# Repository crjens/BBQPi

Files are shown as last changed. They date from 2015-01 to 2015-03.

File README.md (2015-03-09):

BBQPi
=====

Raspberry Pi BBQ meter

Install Instructions
--------------------

1. Start with latest Raspian image from http://downloads.raspberrypi.org/raspbian_latest
2. login to Pi with Putty or other 
3. run 'sudo raspi-config' 
	1. set locale and timezone under internationalisation options
	2. enable SPI and I2C under Advanced Options
	3. expand filesystem
4. Enable I2C by adding the following two lines to /etc/modules
	1. i2c-bcm2708 
	2. i2c-dev
5. Install nodejs:
	1.	wget http://nodejs.org/dist/v0.10.28/node-v0.10.28-linux-arm-pi.tar.gz
	2.	tar -xvzf node-v0.10.28-linux-arm-pi.tar.gz
	3.  create symbolic links to node and npm
		1.	sudo ln -s /home/pi/node-v0.10.28-linux-arm-pi/bin/node /usr/bin/node
		2.	sudo ln -s /home/pi/node-v0.10.28-linux-arm-pi/bin/npm /usr/bin/npm
	4. (both node -v and npm -v should now show current version)
6. Clone BBQPi into app directory
	1. git clone https://github.com/crjens/BBQPi.git app
7. cd into the 'app' directory and type 'npm install'

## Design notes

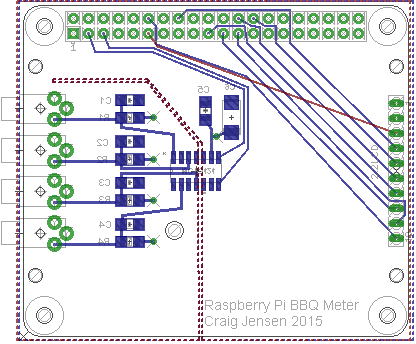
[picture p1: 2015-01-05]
Eagle/BBqP1.png

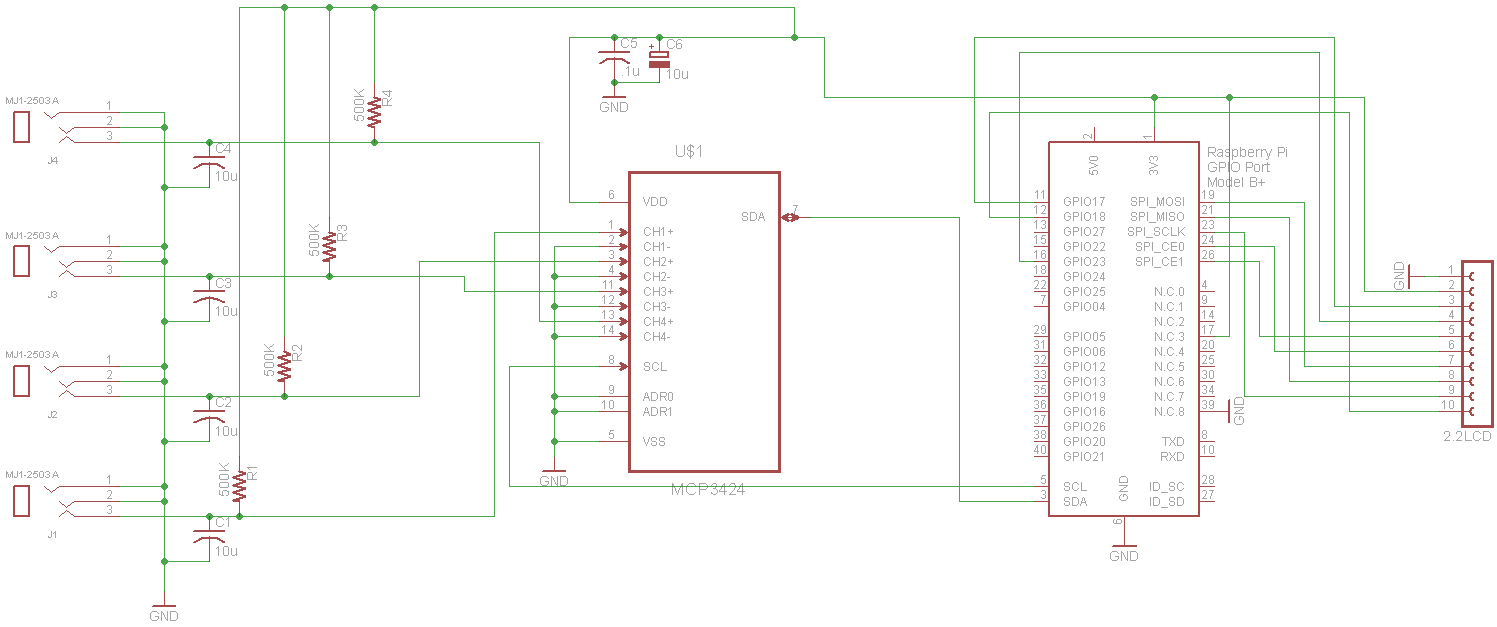
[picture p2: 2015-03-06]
Eagle/BBqP1sch.png

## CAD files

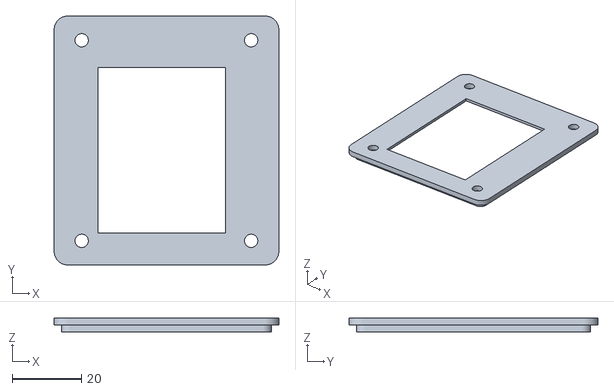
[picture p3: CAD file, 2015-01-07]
3dModels/final pre-critical-measure draft top.stl
65.0 x 72.0 x 4.00

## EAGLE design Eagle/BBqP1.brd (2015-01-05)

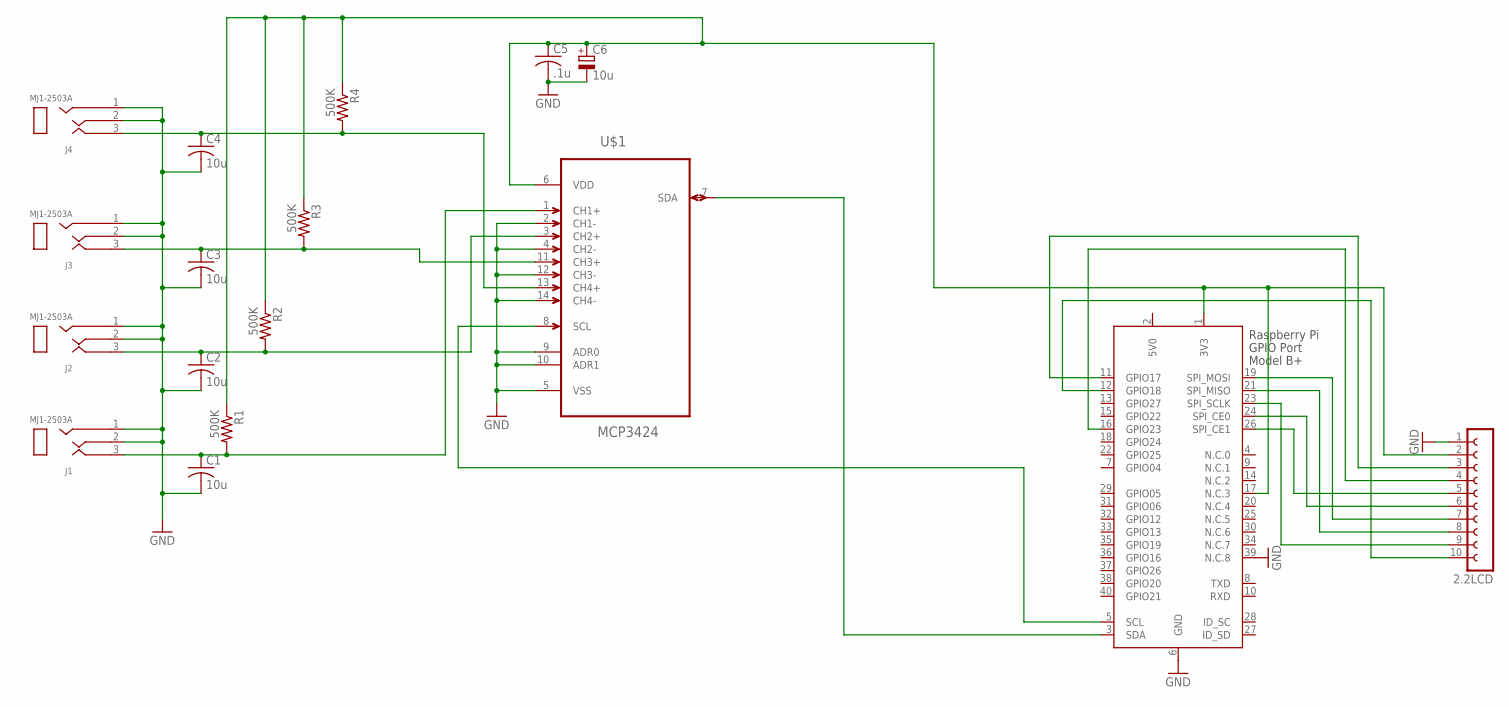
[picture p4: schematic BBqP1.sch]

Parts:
2.2LCD: FE10-1; FE10
C1, C2, C3, C4: 10u; C1206; MPN C1206C106M4RACTU
C5: .1u; C1206; MPN C1206C104K5RACAUTO
C6: 10u; SMC_C; MPN T491C106M016AT
J1, J2, J3, J4: MJ1-2503A
R1, R2, R3, R4: 500K; R1206; MPN CRCW1206510KFKEA
U$1: MCP3424; SOIC127P600X175-14N
X1: RASPI_BOARD_B+_H; RASPI_BOARD_B+HAT

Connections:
3V3: 2.2LCD.2, C5.1, C6.+, R1.1, R2.1, R3.1, R4.1, U$1.6 (VDD), X1.1 (3V3), X1.17 (N.C.3)
5V0: X1.2 (5V0)
GND: 2.2LCD.1, C1.2, C2.2, C3.2, C4.2, C5.2, C6.-, J1.1, J1.2, J2.1, J2.2, J3.1, J3.2, J4.1, J4.2, U$1.2 (CH1-), U$1.4 (CH2-), U$1.5 (VSS), U$1.9 (ADR0), U$1.10 (ADR1), U$1.12 (CH3-), U$1.14 (CH4-), X1.6 (GND), X1.39 (N.C.8)
unnamed: C4.1, J4.3, R4.2, U$1.13 (CH4+)
unnamed: 2.2LCD.10, X1.12 (GPIO18)
unnamed: C3.1, J3.3, R3.2, U$1.11 (CH3+)
unnamed: C2.1, J2.3, R2.2, U$1.3 (CH2+)
unnamed: C1.1, J1.3, R1.2, U$1.1 (CH1+)
unnamed: 2.2LCD.4, X1.16 (GPIO23)
unnamed: 2.2LCD.8, X1.21 (SPI_MISO)
unnamed: U$1.8 (SCL), X1.5 (SCL)
unnamed: 2.2LCD.7, X1.19 (SPI_MOSI)
unnamed: 2.2LCD.6, X1.24 (SPI_CE0)
unnamed: U$1.7 (SDA), X1.3 (SDA)
unnamed: 2.2LCD.5, X1.26 (SPI_CE1)
unnamed: 2.2LCD.9, X1.23 (SPI_SCLK)
unnamed: 2.2LCD.3, X1.11 (GPIO17)

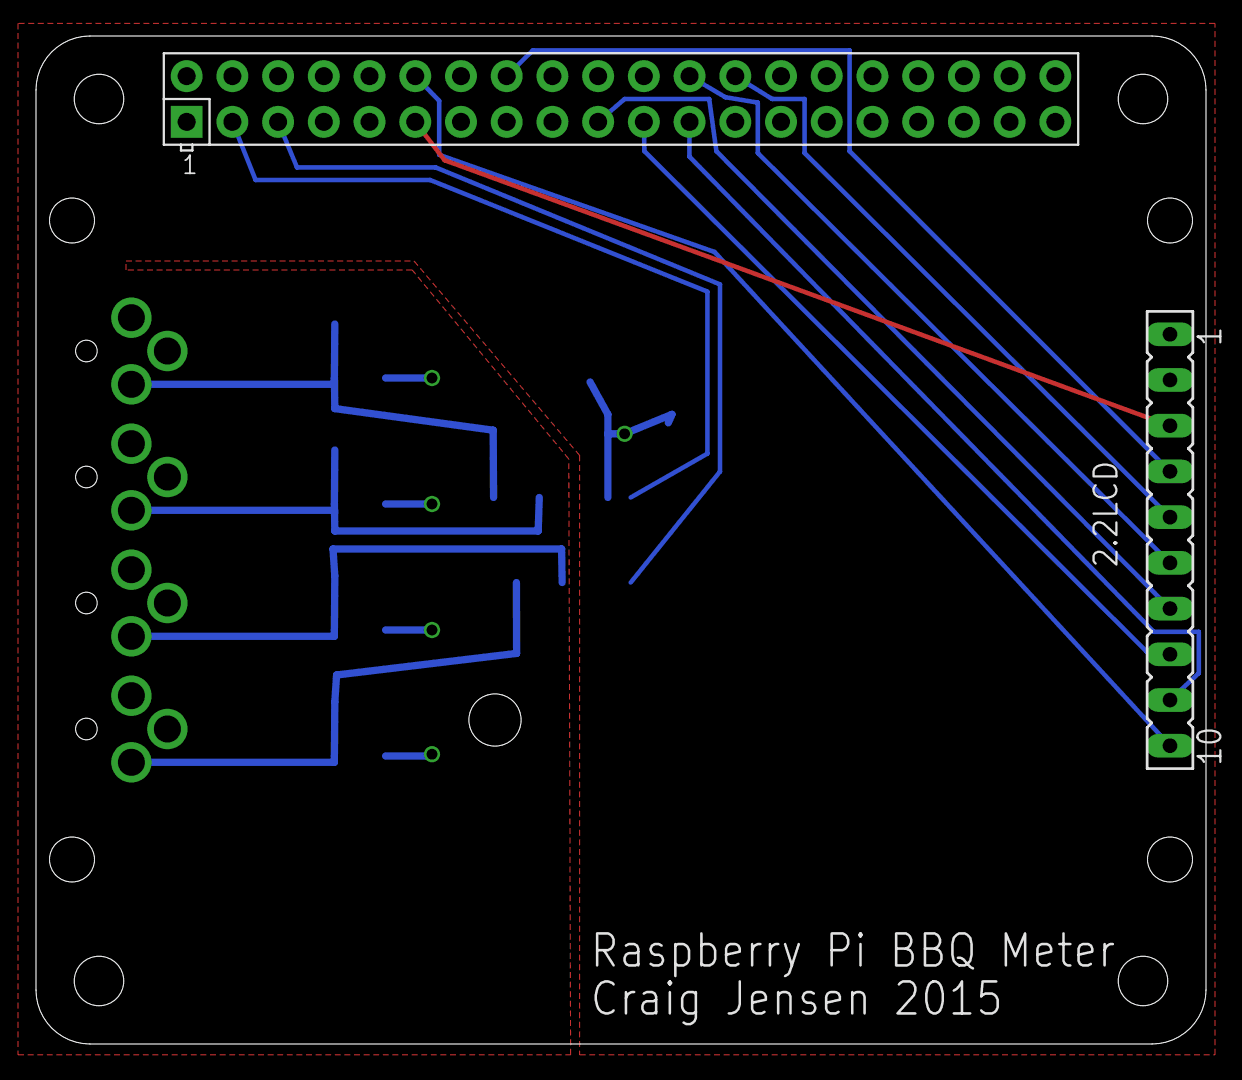
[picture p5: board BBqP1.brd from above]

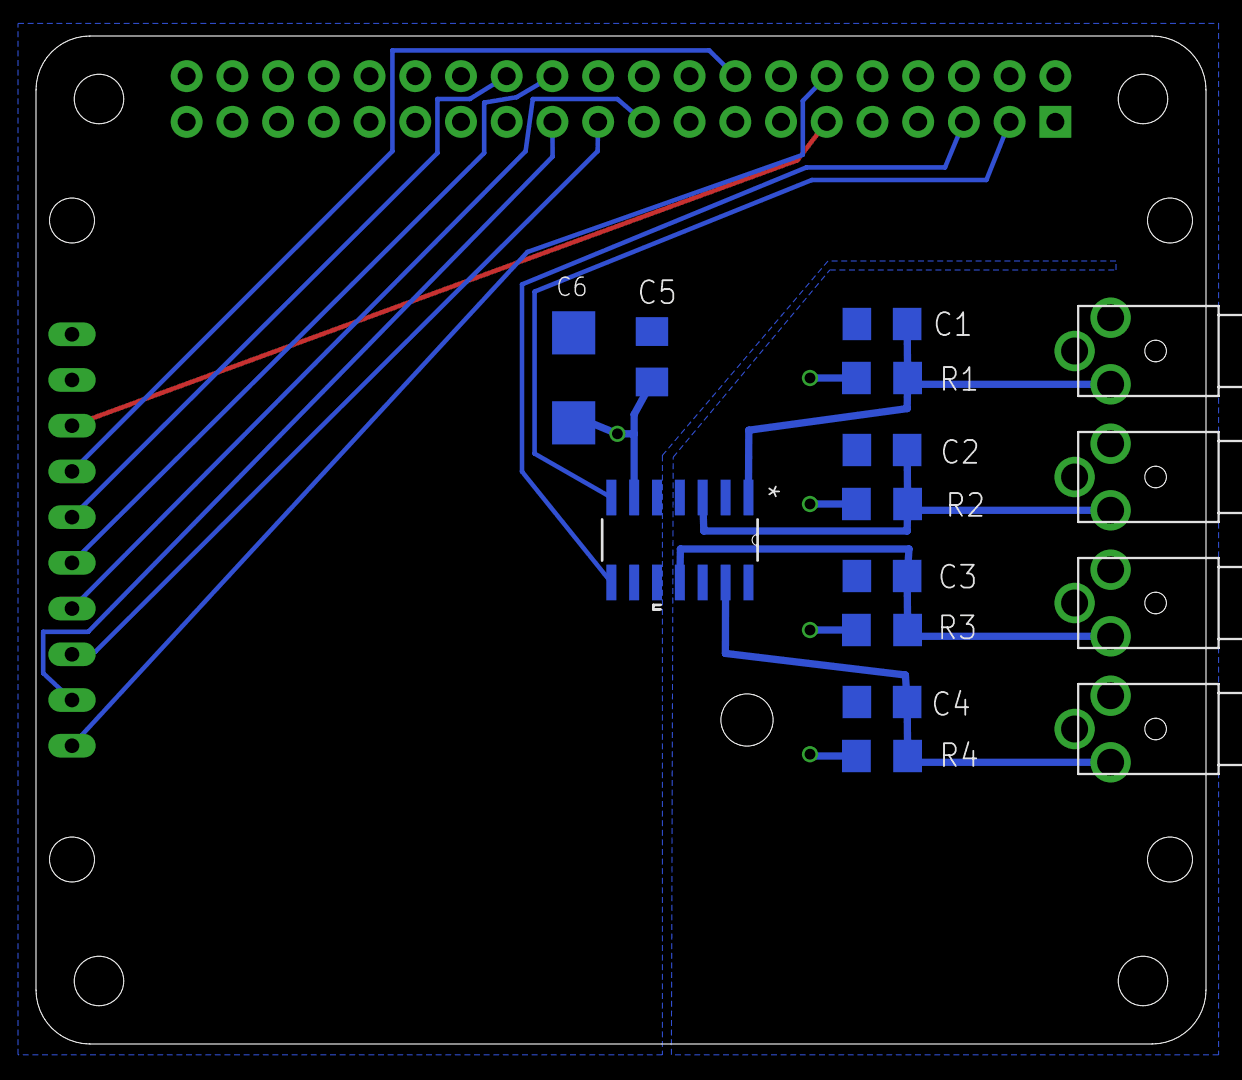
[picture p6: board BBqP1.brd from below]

Board: 2 copper layers, 65.0 x 56.0 mm, 17 parts (15 on the bottom side), 16 nets.

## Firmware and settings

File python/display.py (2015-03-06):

import Image
import ImageDraw
import ImageFont
import sys, json, datetime

import Adafruit_ILI9341 as TFT
import Adafruit_GPIO as GPIO
import Adafruit_GPIO.SPI as SPI


# Raspberry Pi configuration.
DC = 17
RST = 23
SPI_PORT = 0
SPI_DEVICE = 0

# BeagleBone Black configuration.
# DC = 'P9_15'
# RST = 'P9_12'
# SPI_PORT = 1
# SPI_DEVICE = 0

# x,y coordinates of plot area
#plotxy = (5,5,185,295)
plotxy = (0,0,225,295)

# load input data
for line in sys.stdin:
  data = json.loads(line)
#  print json.dumps(data)

# Define a function to create rotated text.  Unfortunately PIL doesn't have good
# native support for rotated fonts, but this function can be used to make a 
# text image and rotate it so it's easy to paste in the buffer.
def draw_rotated_text(image, text, position, font, fill=(255,255,255), halign='top', valign='right'):
	# Get rendered font width and height.
	draw = ImageDraw.Draw(image)
	width, height = draw.textsize(text, font=font)
	# Create a new image with transparent background to store the text.
	textimage = Image.new('RGBA', (width, height), (0,0,0,0))
	#textimage = Image.new('RGBA', (width, height), (255,0,0))
	# Render the text.
	textdraw = ImageDraw.Draw(textimage)
	textdraw.text((0,0), text, font=font, fill=fill)
	# Rotate the text image.
	rotated = textimage.rotate(90, expand=1)
	#draw.line((position[0]-5, position[1]-5, position[0]+5, position[1]+5), fill=(255,255,255))
	#draw.line((position[0]-5, position[1]+5, position[0]+5, position[1]-5), fill=(255,255,255))
	# adjust position
	if valign=='center':
		position = (position[0]-height/2, position[1])
	elif valign=='bottom':
		position = (position[0]-height, position[1])
	if halign=='center':
		position = (position[0], position[1]-width/2)
	elif halign=='left':
		position = (position[0], position[1]-width)
	# Paste the text into the image, using it as a mask for transparency.
	image.paste(rotated, position, rotated)
	

# plot temps on graph
def plot(temps, color):
	lastx=0
	lasty=0
	for i,val in enumerate(temps):
		x = plotxy[2] - ((temps[i]-yrange[0])/float(yrange[1]-yrange[0]))*(plotxy[2]-plotxy[0])
		y = plotxy[3] - ((data["time"][i]-xrange[0])/float(xrange[1]-xrange[0]))*(plotxy[3]-plotxy[1])
		draw.rectangle((x-2,y-2,x+2, y+2), fill=color, outline=color)	
		if i>0:
			draw.line((lastx, lasty, x, y), fill=color, width=1)	
		lastx=x
		lasty=y

# find min and max temps
def minmax (list):
    if list is None or len(list) == 0:
        return (0.0,0.0)

    minimum = maximum = list[0]
    for i in list[1:]:
        if i < minimum: 
            minimum = i 
        else: 
            if i > maximum: maximum = i
    return (minimum,maximum)          

# format timestamp
def formattime(timestamp):
	time = datetime.datetime.fromtimestamp(timestamp/1000.0)
	if time.hour > 12:
		return "%d:%02d" % (time.hour-12, time.minute)
	else:
		return "%d:%02d" % (time.hour, time.minute)
	#return datetime.datetime.fromtimestamp(timestamp/1000.0).strftime('%I:%M')


# load fonts
font = ImageFont.truetype('fonts/segoeui.ttf', 18)
font2 = ImageFont.truetype('fonts/segoeui.ttf', 12)

# find min max ranges for input data
yrange = minmax(data["probe1"]+data["probe2"]+data["probe3"]+data["probe4"])
xrange = minmax(data["time"])

# add 5% padding to data ranges
pad = (yrange[1]-yrange[0])*0.05 + 1.0;
yrange = (yrange[0]-pad, yrange[1]+pad)

# make sure x has a range so don't hit a divde by zero errorrange
if xrange[0]==xrange[1]:
	xrange = (xrange[0]-60000, xrange[1]+60000)

# Create TFT LCD display class.
disp = TFT.ILI9341(DC, rst=RST, spi=SPI.SpiDev(SPI_PORT, SPI_DEVICE, max_speed_hz=64000000))

# Initialize display.
disp.begin()

# clear display to black:
disp.clear((0,0,0))

# Get a PIL Draw object to start drawing on the display buffer.
draw = disp.draw()

# Draw graph rectangle
draw.line((plotxy[0], plotxy[1], plotxy[2], plotxy[1]), fill=(255,255,255))
draw.line((plotxy[2], plotxy[1], plotxy[2], plotxy[3]), fill=(255,255,255))
draw.line((plotxy[2], plotxy[3], plotxy[0], plotxy[3]), fill=(255,255,255))
draw.line((plotxy[0], plotxy[3], plotxy[0], plotxy[1]), fill=(255,255,255))

# horizontal gridlines and labels
offset = (plotxy[2]-plotxy[0]) / 4
for i in range(5):
	if i>0 and i<4:
		draw.line((plotxy[2]-offset*i, plotxy[1], plotxy[2]-offset*i, plotxy[3]), fill=(50,50,50))
	if i==0: align='bottom'
	elif i==4: align='top'
	else: align='center'
	draw_rotated_text(disp.buffer, "%3d" % (yrange[0] + ((yrange[1]-yrange[0])/4.0)*i), (plotxy[2]-offset*i, plotxy[3]+5), font2, fill=(255,255,255), valign=align)

# vertical gridlines and labels
offset = (plotxy[3]-plotxy[1]) / 5
for i in range(6):
	if i>0 and i<5:
		draw.line((plotxy[0], plotxy[0] + offset*i, plotxy[2], plotxy[0] + offset*i), fill=(50,50,50))
	if i==0: align='left'
	elif i==5: align='right'
	else: align='center'
	draw_rotated_text(disp.buffer, formattime(xrange[0] + ((xrange[1]-xrange[0])/5.0)*i), (plotxy[2], plotxy[3]-offset*i), font2, fill=(255,255,255), halign=align)



# plot probe temps
if len(data["probe1"]) > 1:
	plot(data["probe1"], (255,0,0))
if len(data["probe2"]) > 1:
	plot(data["probe2"], (0, 255,0))
if len(data["probe3"]) > 1:
	plot(data["probe3"], (0, 0, 255))
if len(data["probe4"]) > 1:
	plot(data["probe4"], (255,255,0))

# draw text for current probe temps
#draw_rotated_text(disp.buffer, "%s: %3d %s" % (data["probe1label"], data["probe1"][0], data["templabel"]), (200, 310), font, fill=(255,0,0), halign='left')
#draw_rotated_text(disp.buffer, "%s: %3d %s" % (data["probe2label"], data["probe2"][0], data["templabel"]), (220, 310), font, fill=(0, 255,0), halign='left')
#draw_rotated_text(disp.buffer, "%s: %3d %s" % (data["probe3label"], data["probe3"][0], data["templabel"]), (200, 10), font, fill=(0, 0, 255), halign='right')
#draw_rotated_text(disp.buffer, "%s: %3d %s" % (data["probe4label"], data["probe4"][0], data["templabel"]), (220, 10), font, fill=(255,255,0), halign='right')

x = 10
if len(data["probe1"]) > 0:
	draw_rotated_text(disp.buffer, "%s: %3d %s" % (data["probe1label"], data["probe1"][len(data["probe1"])-1], data["templabel"]), (x, 280), font, fill=(255,0,0), halign='left')
	x = x+20
if len(data["probe2"]) > 0:
	draw_rotated_text(disp.buffer, "%s: %3d %s" % (data["probe2label"], data["probe2"][len(data["probe2"])-1], data["templabel"]), (x, 280), font, fill=(0, 255,0), halign='left')
	x = x+20
if len(data["probe3"]) > 0:
	draw_rotated_text(disp.buffer, "%s: %3d %s" % (data["probe3label"], data["probe3"][len(data["probe3"])-1], data["templabel"]), (x, 280), font, fill=(0, 0, 255), halign='left')
	x = x+20
if len(data["probe4"]) > 0:
	draw_rotated_text(disp.buffer, "%s: %3d %s" % (data["probe4label"], data["probe4"][len(data["probe4"])-1], data["templabel"]), (x, 280), font, fill=(255,255,0), halign='left')

# Write buffer to display hardware, must be called to make things visible on the display!
disp.display()

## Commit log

2015-01-05 Add Eagle files
    [BBqP1.brd, BBqP1.sch]
2015-01-07 Adding 3d files
    This set is pre-board measurements, they are close, but may be slightly
    off. Final adjustments will not be fun.
    [final pre-critical-measure draft top.stl]
2015-01-08 fixed i2c version
2015-01-08 Bug fixes and cleanup
    [display.py]
2015-03-09 updated readme and i2c version
2015-03-09 revert version of i2c
2015-03-09 rerevert i2c version

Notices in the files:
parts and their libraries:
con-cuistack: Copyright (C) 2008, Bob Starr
